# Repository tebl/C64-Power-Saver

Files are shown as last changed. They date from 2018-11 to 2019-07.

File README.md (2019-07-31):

# C64 Power Saver
This is a project I started a few years back after buying the components to build one from console5.com, but as so many of them I didn't take it past the breadboard and ended up with yet another pile of components that sort of works. Now, with a few rainy days past I've finally found the time to draw it out in KiCAD and make a few boards for this project - the first one I used the wrong pinouts so I made a PCB saver that only connects with bad power supplies, then I made one that melted. Third times the charm and this one is working great, so might have to start looking into building a bunch of them for the rest of my C64s.

Why you'd need one in the first place, you say? Basically, Commodore intended the computer to live a maximum of 5-6 years and so the components chosen reflected this - no thought went into considering what happens past this point. Now that it's 30 years later we know that the 5v regulator has a tendency to short out input and output voltage, meaning that those sensitive 5v chips will intermittenly, or sometimes even permanently, end up getting something like two or three times that... enough to melt that precious silicon! Your options are either to get a brand new power supply or combine your old one with a C64 power saver for as long as that'll still be around, running unprotected is simply foolish these days!

How does it work? The design is based on the one developed by famed C64-tinkerer Ray Carlsen, what it does is monitor the 5v line coming from your power supply and when it starts outputting voltages above 5.6v a relay is slammed shut and the line is cut. You have the option of mounting a buzzer to the board so that you can get annoyed at it until you realize it's time to buy or build a new PSU, or when mounted externally you can look at the nice LEDs to figure out wether your supply is good or not. Once a PSU has started to go bad, put a "Bad PSU" sticker on it and never use it again! For details on where to cut and solder internally on the computer see Ray Carlsens [website](http://personalpages.tds.net/~rcarlsen/cbm/c64/SAVER/MOBOs/).

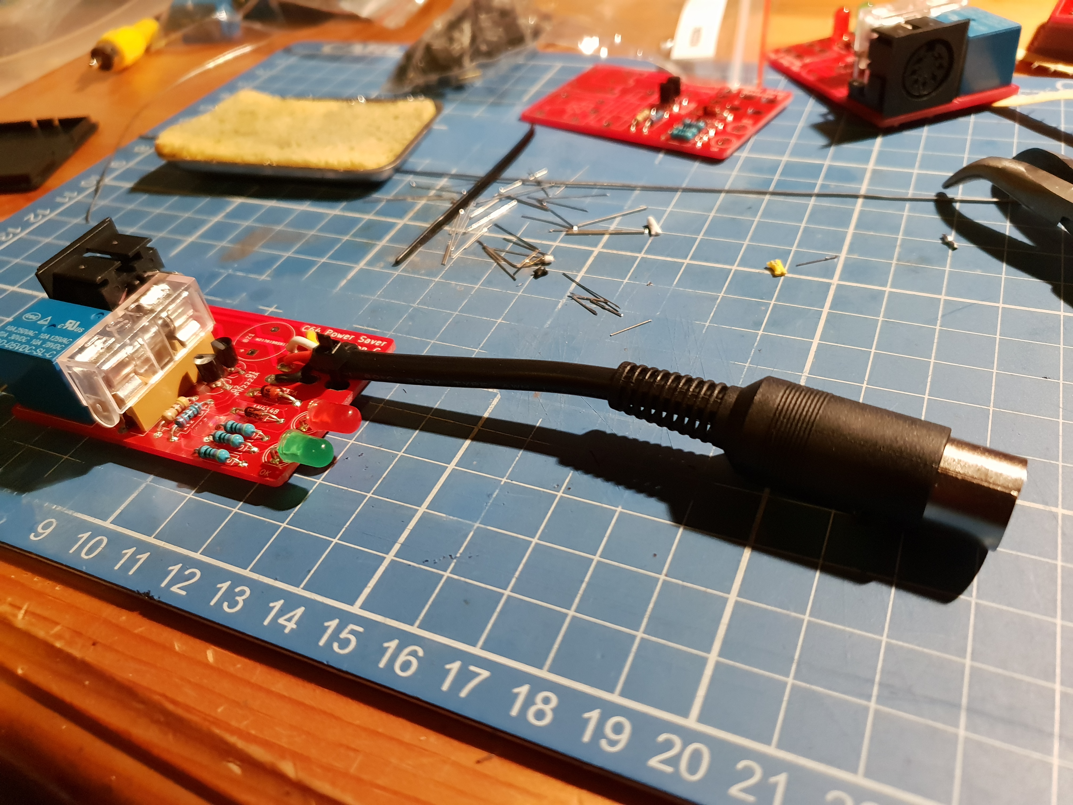
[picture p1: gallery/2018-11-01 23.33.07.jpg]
Bare PCB

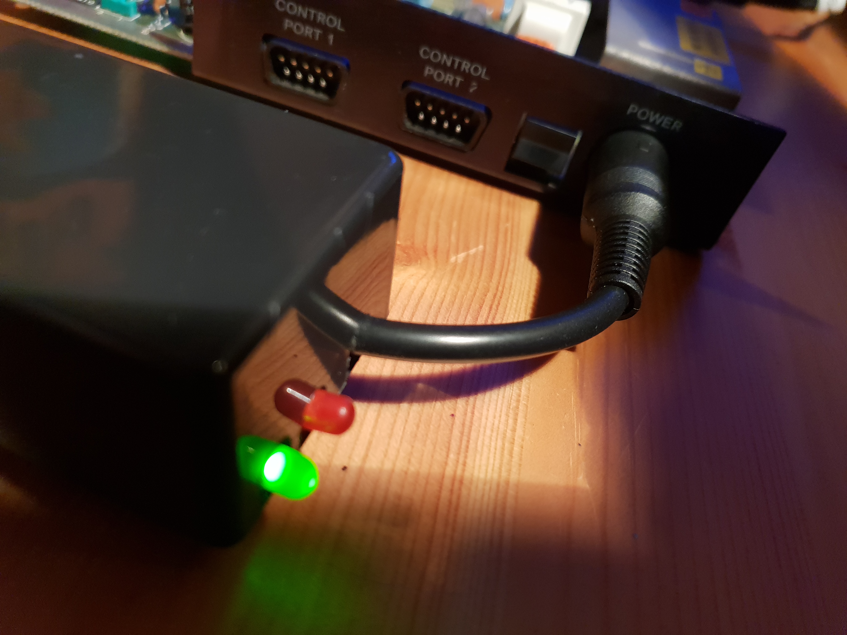
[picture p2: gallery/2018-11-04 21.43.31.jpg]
Boxed up and connected


## Errata
**Revision C/D**
It has come to my attention that some original Commodore 64 power supplies were wired differently, specifically sometimes 5v would be supplied on the opposite pin - this is easily fixed by connecting a small piece of wire across DIN pins 4 and 5. Refer to this [image](https://github.com/tebl/C64-Power-Saver/raw/master/gallery/revision_d_fix.PNG), the board outline is shown from above and the wire you need to add is the green one.

# Schematic
The supplied KiCad files should be sufficient as both a schematic and as a  starting point for ordering PCBs (basically you could just zip the contents of the export folder and upload that on a fabrication site), the schematic is also available in [PDF-format](https://github.com/tebl/C64-Power-Saver/raw/master/export/C64%20Power%20Saver.pdf) and this is what you'll need to print and work your way through this things don't work as expected after assembly.

# BOM
Most parts should be easy to get a hold of from your favourite local electronic component shop though you might have to consider other sources for the older parts such as the CPU and memory. Personally I bought most components with free shipping from China via AliExpress - prices will vary, but I found everything in larger quantities than needed for the cost of a few cups of fancy coffee! Last couple of components listed are for making the cable that goes from the power saver and into your C64, not needed if the module is to be mounted internally in the computer.

| Reference | Item | Count |
| --- | --- | ----- |
| PCB | Fabricate using Gerber files ([order](https://www.pcbway.com/project/shareproject/W217819ASN17_C64_Power_Saver.html?inviteid=88707))  | 1 |
| D1 | 1N4732A DO-35 | 1 |
| D2 | 1N4148 DO-35, alternatively 1N914 | 1 |
| D3 | 5mm LED (green) | (1) |
| D4 | 5mm LED (red) | 1 |
| F1 | Fuse holder, with 1A fast acting fuse | 1 |
| J5 | 7pin DIN socket PCB mount | (1) |
| K1 | SRD-5VDC-SL-C 5v relay | 1 |
| Q1, Q2 | 2N2222 TO-92 transistor | 2 |
| R1,R2,R4,R5  | 470 ohm resistor | 4 |
| R3 | 2k2 ohm (2200) resistor | 1 |
| BZ1 | 5v active buzzer, 7.6mm pin spacing | 1 |
| | 4-core wire | (1) |
| | 7pin male DIN plug | (1) |
| | 70x45x30mm electronic project box | (1) |

Please use the order link above when signing up to help me support this project, I'll get a small discount on future orders and hopefully that means I can afford to keep developing new and exciting modules in the future. By using the URL you won't have to deal with the rather daunting order forms for PCB fabrication, but if you want to go that route they'll probably want a zipped-up copy of the files in the export-directory!

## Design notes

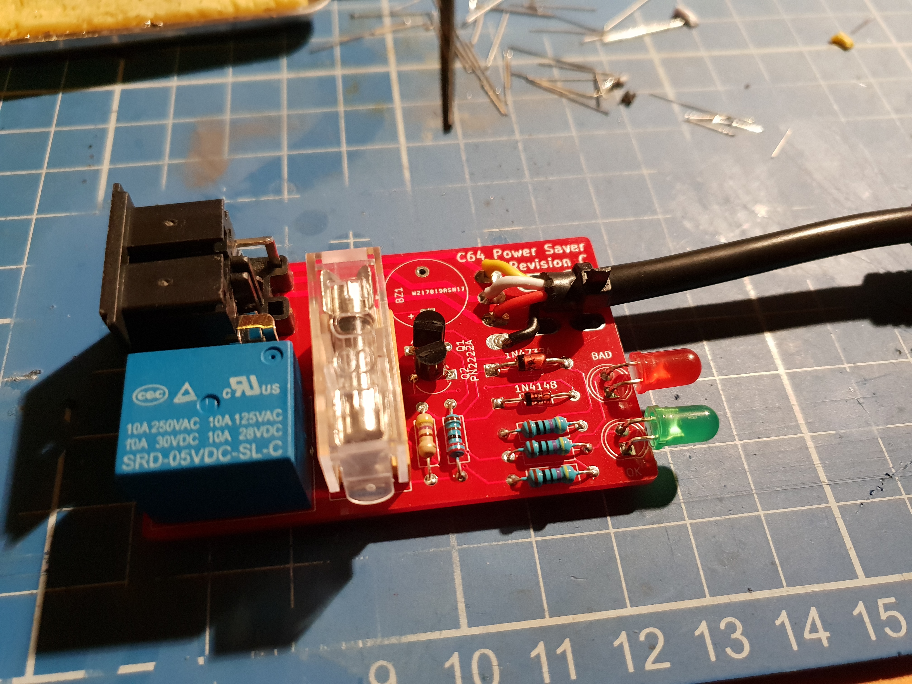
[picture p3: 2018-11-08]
gallery/2018-11-01 23.32.59.jpg

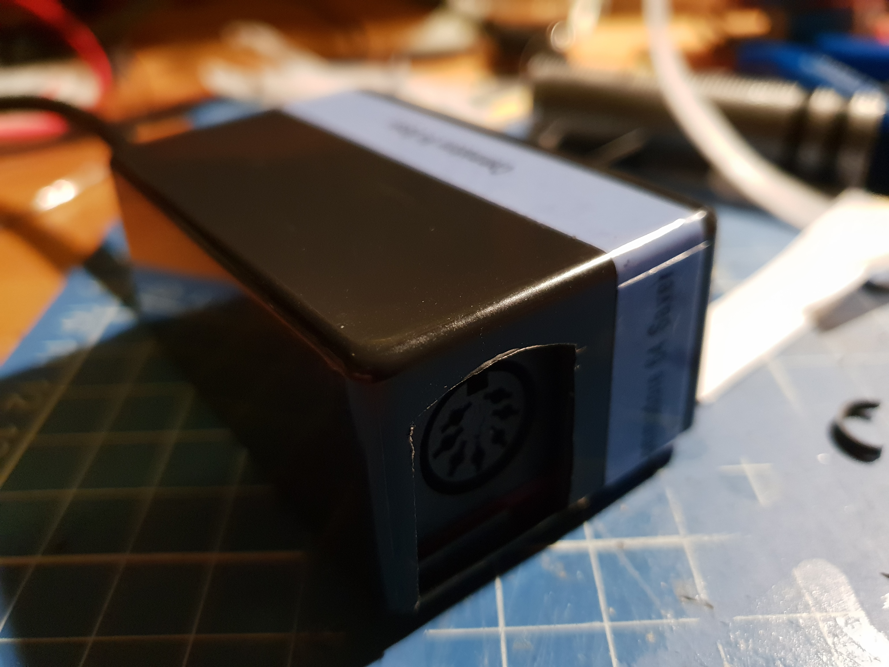
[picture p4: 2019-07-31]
gallery/2018-12-01 17.35.05.jpg

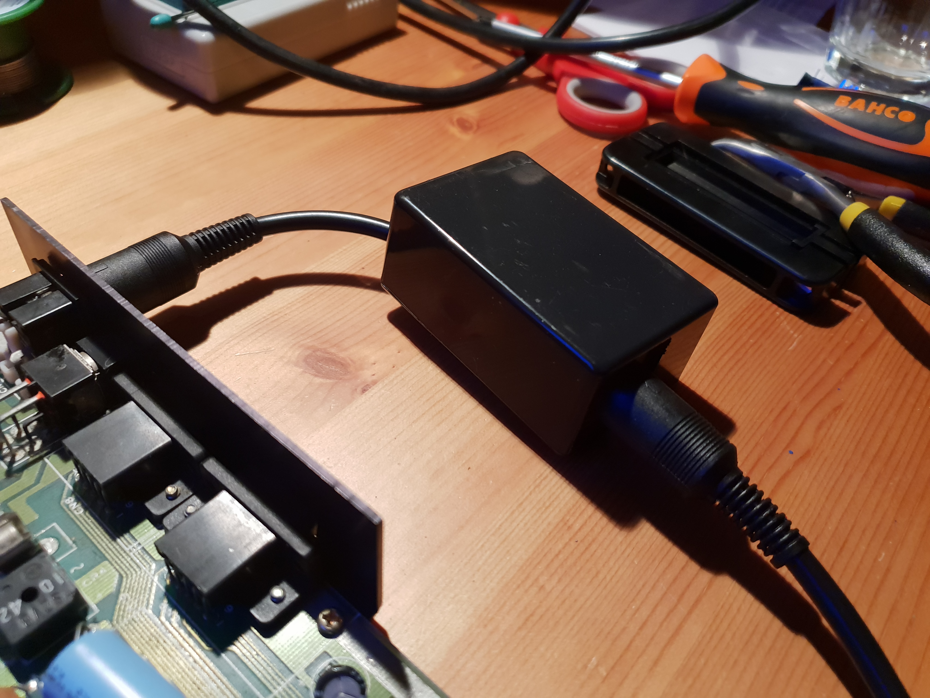
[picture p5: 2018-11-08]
gallery/2018-11-04 21.43.22.jpg

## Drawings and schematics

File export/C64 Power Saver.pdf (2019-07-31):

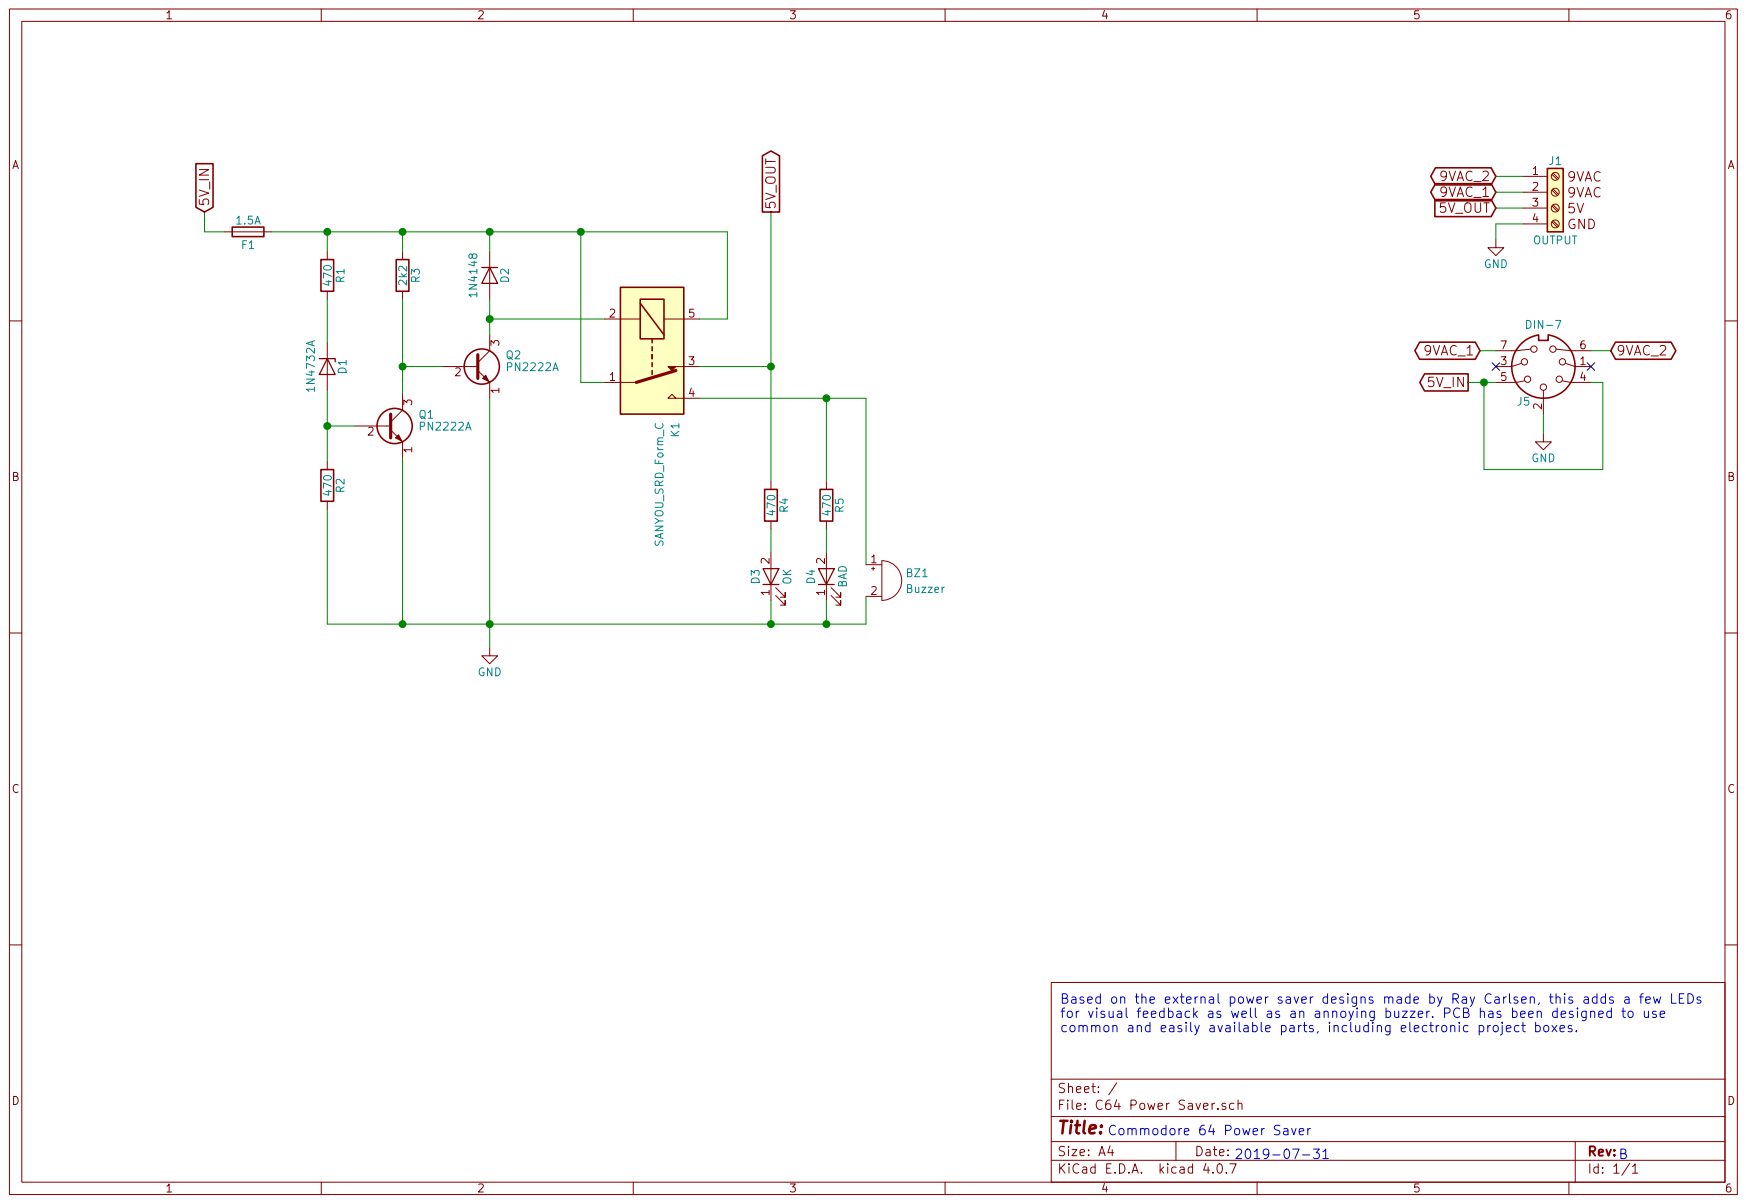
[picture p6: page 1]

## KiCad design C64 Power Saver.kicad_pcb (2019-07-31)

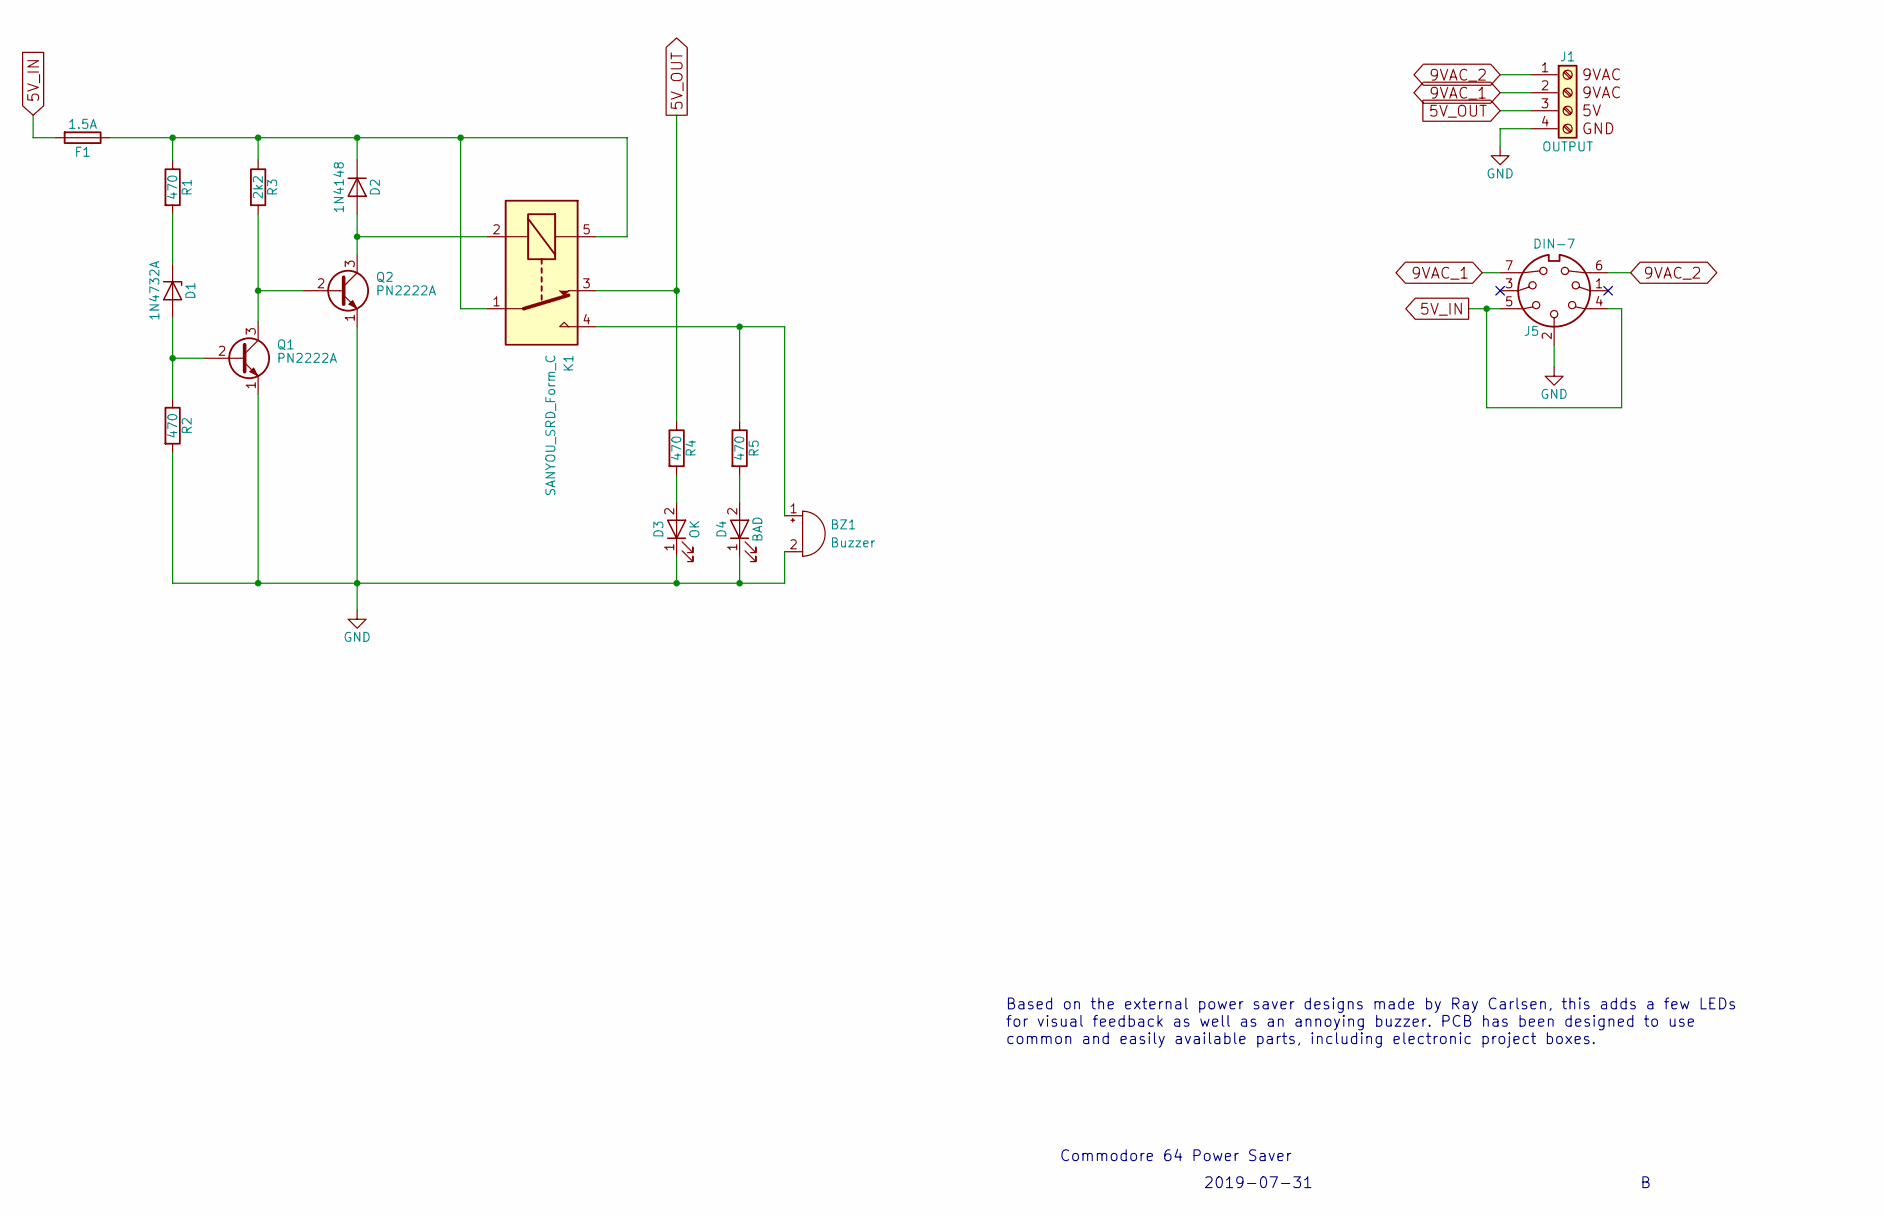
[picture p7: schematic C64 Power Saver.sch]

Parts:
BZ1: Buzzer; Buzzer_12x9.5RM7.6
D1: 1N4732A; D_T-1_P10.16mm_Horizontal
D2: 1N4148; D_DO-35_SOD27_P10.16mm_Horizontal
D3: OK; LED_D5.0mm
D4: BAD; LED_D5.0mm
F1: 1.5A; Fuseholder5x20_horiz_SemiClosed_Casing10x25mm
J1: OUTPUT; OUTPUT_ZIP
J5: DIN-7; C64_PWR
K1: SANYOU_SRD_Form_C; Relay_SPDT_SANYOU_SRD_Series_Form_C
Q1, Q2: PN2222A; TO-92_Inline_Wide
R1, R2, R4, R5: 470; R_Axial_DIN0207_L6.3mm_D2.5mm_P10.16mm_Horizontal
R3: 2k2; R_Axial_DIN0207_L6.3mm_D2.5mm_P10.16mm_Horizontal

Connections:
5V_IN: F1.2, J5.4, J5.5
5V_OUT: J1.3, K1.3, R4.1
9VAC_1: J1.2, J5.7
9VAC_2: J1.1, J5.6
GND: BZ1.2 (+), D3.1 (K), D4.1 (K), J1.4, J5.2, Q1.1 (E), Q2.1 (E), R2.2
unnamed: BZ1.1 (-), K1.4, R5.1
unnamed: D1.1 (K), R1.2
unnamed: D1.2 (A), Q1.2 (B), R2.1
unnamed: D2.1 (K), F1.1, K1.1, K1.5, R1.1, R3.1
unnamed: D2.2 (A), K1.2, Q2.3 (C)
unnamed: D3.2 (A), R4.2
unnamed: D4.2 (A), R5.2
unnamed: Q1.3 (C), Q2.2 (B), R3.2

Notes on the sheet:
Commodore 64 Power Saver
Based on the external power saver designs made by Ray Carlsen, this adds a few LEDs for visual feedback as well as an annoying buzzer. PCB has been designed to use common and easily available parts, including electronic project boxes.
2019-07-31

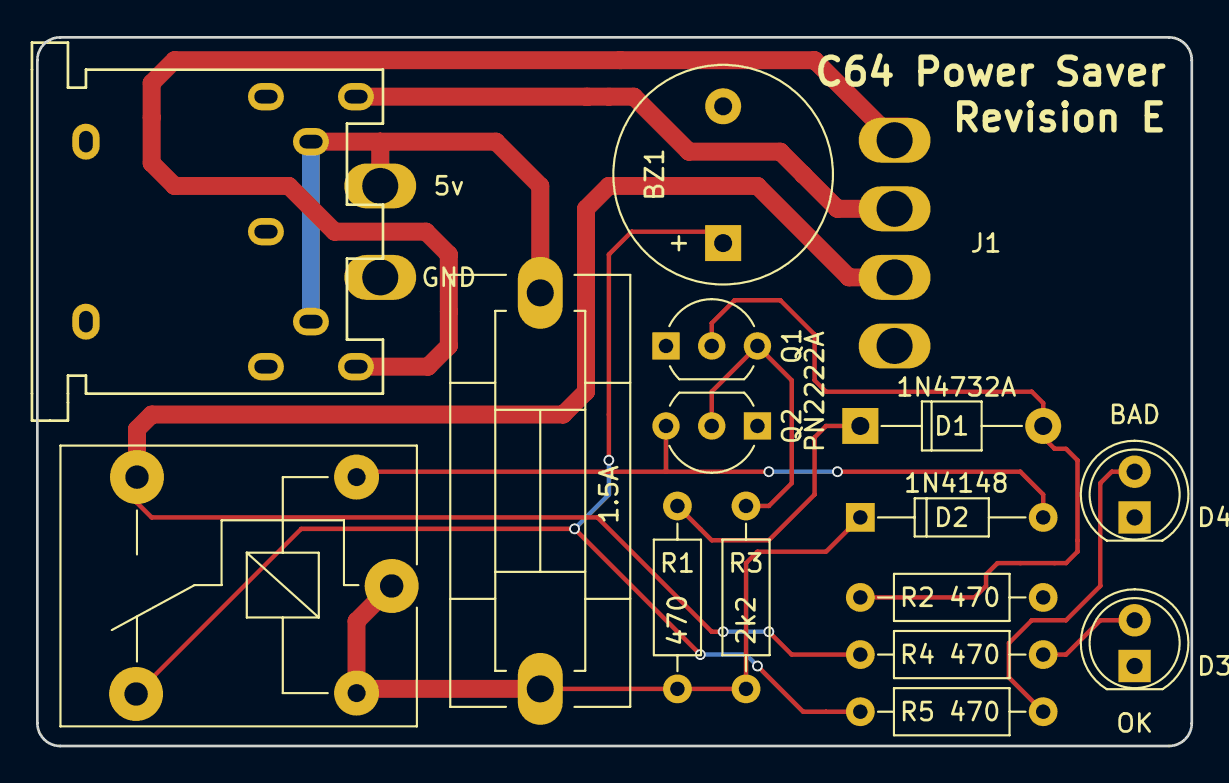
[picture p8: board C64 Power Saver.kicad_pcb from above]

Board: 2 copper layers, 64.1 x 39.4 mm, 16 parts (0 on the bottom side), 13 nets.

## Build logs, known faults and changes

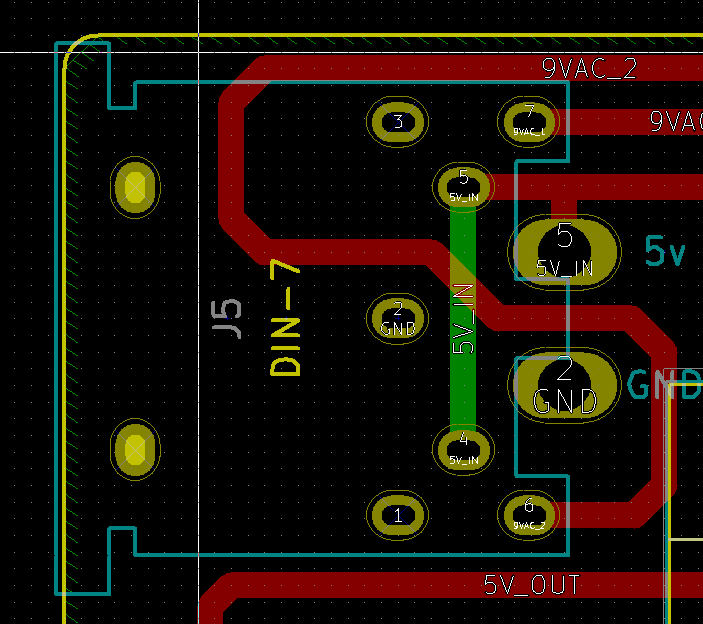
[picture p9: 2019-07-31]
gallery/revision_d_fix.PNG

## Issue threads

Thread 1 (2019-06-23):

Add 5V in DIN-7 pin 4

bwack, 2019-06-23:
Hi. I saw your post on lemon64. Just a heads up with my experience with selling savers. You should add 5V on DIN-7 pin 4. Less returns from people who have power supplies with 5V pin on the other side of the GND pin.

tebl, 2019-07-31:
I have adjusted the PCB as well as added a notice for people looking for a solution for PCBs already built. I have only built a handful of these myself, I'm not on lemon64 myself so thank you for bringing this to my attention :-)

bwack, 2019-08-01:
Got an thank-you message from the guy on lemon64, and I was surprised his name was not tebl hehe.

Closed 2019-08-04.

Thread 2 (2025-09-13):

Not cutting power at 5.4v or more

hartraver, 2025-09-13:
I´ve bought your C64 Powersaver from a local dealer. It came unassembled. I have assembled it and wanna test the cut off ,but it wont cut the power even though I´m up to 5.8v. It also gives 5.8v out to the C64 plug at the same time.
I´m using a DC Regulated Power supply given from 0-15v and 0-2amps to test with.

The LED stays green from 5v and up
if I go BELOW 5v,then the RED LED turns on and no voltage is coming out to the C64.

The guy I bought from ,have seen a picture of my assembly and could not find any errors.
He has sold and tested a few,but tested with a defect C64 PSU, putting out 5.7v and every he has sold/build ,has worked.He has never tested with variable DC.

When i attach the c64 PSU which gives 10v AC and 5.13v DC, the exact same output is measured in the plug for C64

hartraver, 2025-09-22:
So..this is just a dead end ??

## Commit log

2018-09-02 Basic schematic completed
    [C64 Power Saver.kicad_pcb, C64 Power Saver.sch]
2018-09-02 Added screw terminals for 9VAC
    [C64 Power Saver.sch]
2018-09-02 PCB layout done
    [C64 Power Saver.sch]
2018-09-02 DIN connector sketch (pads need measuring)
    [C64 Power Saver.sch]
2018-09-02 Gerber export (without 7 pin din)
    [C64 Power Saver-B.Cu.gbl, C64 Power Saver-B.Mask.gbs, C64 Power Saver-B.Paste.gbp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]
2018-09-26 Oh... So I made a saver that works only on bad ones... Rev. B!
    [C64 Power Saver-B.Cu.gbl, C64 Power Saver-B.Mask.gbs, C64 Power Saver-B.Paste.gbp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]
2018-09-30 Updated schematic to use DIN connector and wire points
    [C64 Power Saver.sch]
2018-09-30 PCB layout redone with DIN connector and added 5v buzzer
    [C64 Power Saver-B.Cu.gbl, C64 Power Saver-B.Mask.gbs, C64 Power Saver-B.Paste.gbp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]
2018-10-15 Fixed groundplane and made wire solder points larger
    [C64 Power Saver-B.Cu.gbl, C64 Power Saver-B.Mask.gbs, C64 Power Saver-B.Paste.gbp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]
2018-11-08 Added wire pads for +5v and GND for thicker wires when internal mounting
    [C64 Power Saver-B.Cu.gbl, C64 Power Saver-B.Mask.gbs, C64 Power Saver-B.Paste.gbp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]
2018-11-08 Updated readme with BOM and images
2018-11-08 Added project box to BOM
2018-11-08 Added proper PCB link
2019-07-31 Add 5v to DIN-7 pin 4
    [C64 Power Saver-B.Cu.gbl, C64 Power Saver-B.Mask.gbs, C64 Power Saver-B.Paste.gbp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]
2019-07-31 Updated gerbers
    [C64 Power Saver-B.Cu.gbl, C64 Power Saver-B.Mask.gbs, C64 Power Saver-B.Paste.gbp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]
